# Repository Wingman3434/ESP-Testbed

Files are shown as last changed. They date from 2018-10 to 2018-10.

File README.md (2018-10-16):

## Introduction

Despite decades of research, home automation has yet to make a significant impact on our everyday lives. Many researchers are developing protocols to remove the need for a central controller. These protocols are often developed for the ESP8266, a low-cost Wi-Fi microcontroller. It can be found on the ESP-01 development module, an 8-pin scaled down version of the full ESP8266 microcontroller. With a lack of an onboard serial controller and voltage regulator, the ESP-01 is difficult to program on a large scale. The ESP-Testbed was created to solve the problem of scalability in these IoT research projects. The concept of the ESP-Testbed is a highly scalable, low-cost prototyping system which allows researchers to test ESP8266 protocols and firmware on a large scale.

## Key Features

- Efficiently Flash many ESP-01 modules with any firmware
- Power a full tower of 15 devices
- Centrally manage a large number of ESP towers
- Test WiFi interference in 3 dimensions
- Communicate with a large number of ESP’s via serial

## Software

The ESP Testbed uses a client-server model via TCP sockets. The Raspberry Pi acts as the client, indefinitely attempting to connect to the server. The user starts the server, which accepts all client connection requests. The server imports data from the configuration file processes it and sends commands to the Raspberry Pi. The client is responsible for interfacing with the ESPs, it controls the Pi’s GPIO pins and serial communication. During programming, the Pi will send progress data back to the server, showing the user progress without the need to connect directly to the tower.

## Make or Buy

The ESP Testbed is a fully open source project, allowing you to download the required files and start building your own towers. This task can be a little daunting so the ESP Testbed team is happy to help. For a small fee, we can assemble, test and ship as many towers as you require.

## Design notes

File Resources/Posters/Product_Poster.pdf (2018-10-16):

# IoT Testbed Tower - Overview

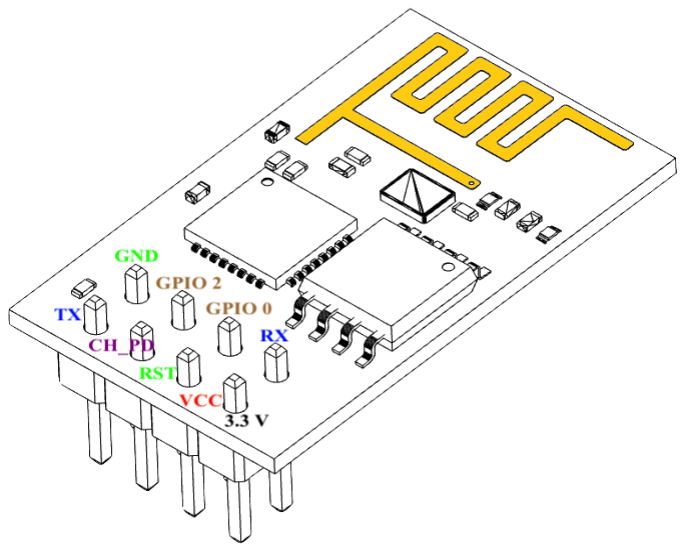
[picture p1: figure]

### Team Name: ESP TESTBED

Student Names: Michael Trifilo, Christopher Rogash School of Engineering, RMIT University, Melbourne, Australia

BACKGROUND & INTRODUCTION

Despite decades of research, home automation has yet to make a significant impact on our everyday lives. Current smart home products rely on the use of a central controller, increasing their cost and complexity.

Our client, Tyler Steane is developing a new IoT protocol which removes the need for a central controller. Steane’s protocol is developed for the ESP8266, a low-cost Wi-Fi microcontroller. It can be found on the ESP-01 development module. With a lack of an onboard serial controller and voltage regulator, the ESP-01 is difficult to program on a large scale.

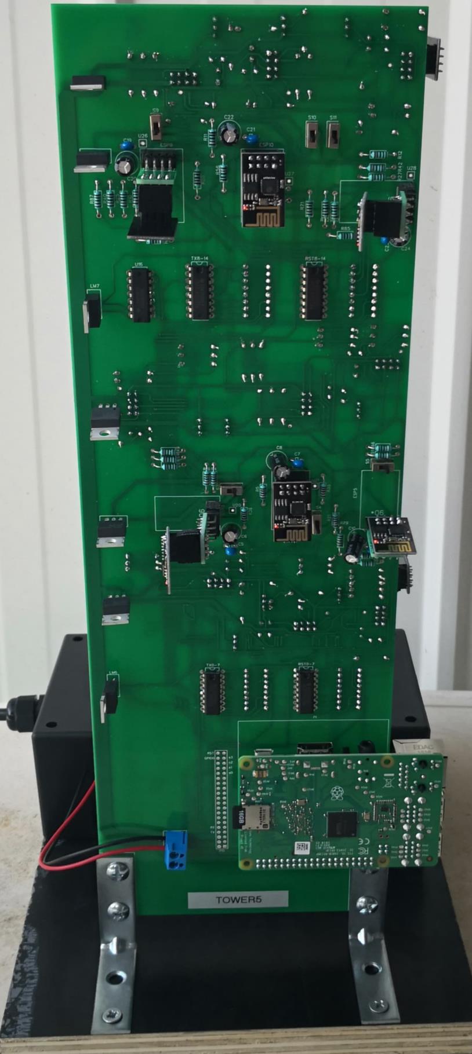
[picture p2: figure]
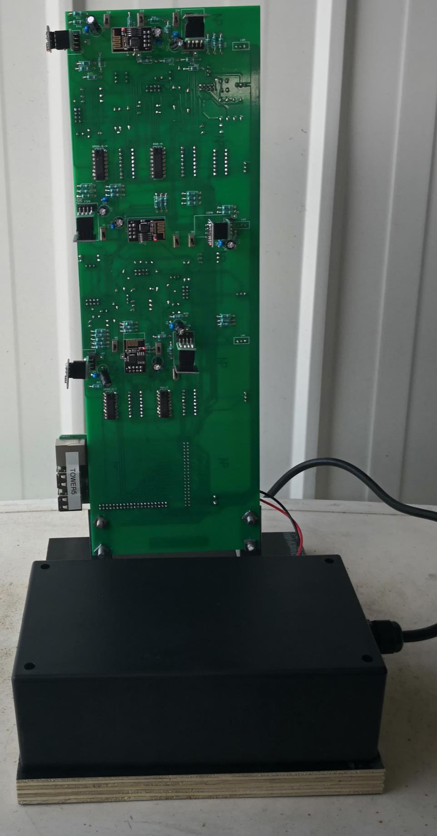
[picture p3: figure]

### www.rmit.edu.au

Figure 3: ESP Tower – Rear View

Figure 2: ESP Tower – Front View

Figure 1: Ai-Thinker ESP-01 Wireframe

ACKNOWLEDGEMENTS
Dr. PJ Radcliffe, PhD student Mr. Tyler Steane

KEY FEATURES
- Efficiently Flash many ESP-01 modules with any firmware.
- Power a full tower of 15 devices.
- Centrally manage a large number of ESP towers.
- Test WiFi interference in 3 dimensions.
- Communicate with a large number of ESP’s via serial.

AIM
Steane’s protocol has been successfully tested on 5 devices. One concern of Steane’s protocol is packet loss due to collision. The ESP Testbed aims to solve this problem by creating compact towers of IoT devices which can be programmed from a single PC. Our goal is to test this on up to 150 devices.

CONCLUSION
The outcome of the ESP Testbed was successful in achieving its initial goal, morphing into a highly scalable, low-cost prototyping system which allows any researcher to test ESP8266 protocols and firmware. The full cost of a tower is approximately $155 AUD with reductions when ordering in bulk. The project has been made open source on GitHub with all documentation, schematics and code made available for anyone to use on their own projects. Further work is planned to continue the development of the ESP Testbed, aiming to increase ease of use and adding extra functionality to the project.

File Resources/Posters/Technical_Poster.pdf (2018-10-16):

# IoT Testbed Tower - Results

DESIGN OF TOWER
Each ESP Tower was made from a set of requirements provided by our client, Tyler Steane. Each tower must:
- Power 15 ESP-01 modules and a Raspberry Pi.
- Provide the ability to remotely program all ESP-01 modules.
- Allow for Wi-Fi testing in 3 dimensions.
- Stand vertically with a sturdy footing.

The PCB’s are split into 4 distinct component sections.
These | are | power, | Pi | control, | communication | via
multiplexers, and the ESP-01 modules.

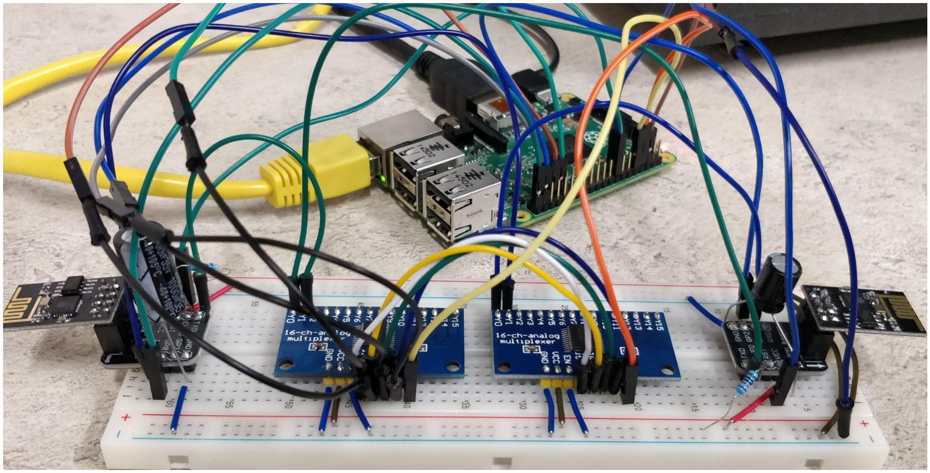
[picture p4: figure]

### www.rmit.edu.au

PROGRAMMING
The ESP Testbed uses a client-server model via TCP sockets. The Raspberry Pi acts as the client, indefinitely attempting to connect to the server. The user starts the server, which accepts all client connection requests. The server imports data from the configuration file, processes it and sends commands to the Raspberry Pi. The client is responsible for interfacing with the ESPs, it controls the Pi’s GPIO pins and serial communication. During programming the Pi will send progress data back to the server, showing the user progress without the need to connect directly to the tower.

KEY ACHIEVEMENTS
- Schematic & PCB Design
- Electronic Prototyping
- PCB Manufacture & Troubleshooting
- Mastering Python Networking
- IoT Development in Arduino IDE
- Plant UML – Diagram design language
- Team Communication Skills
- Time Management
- Formal Report Writing

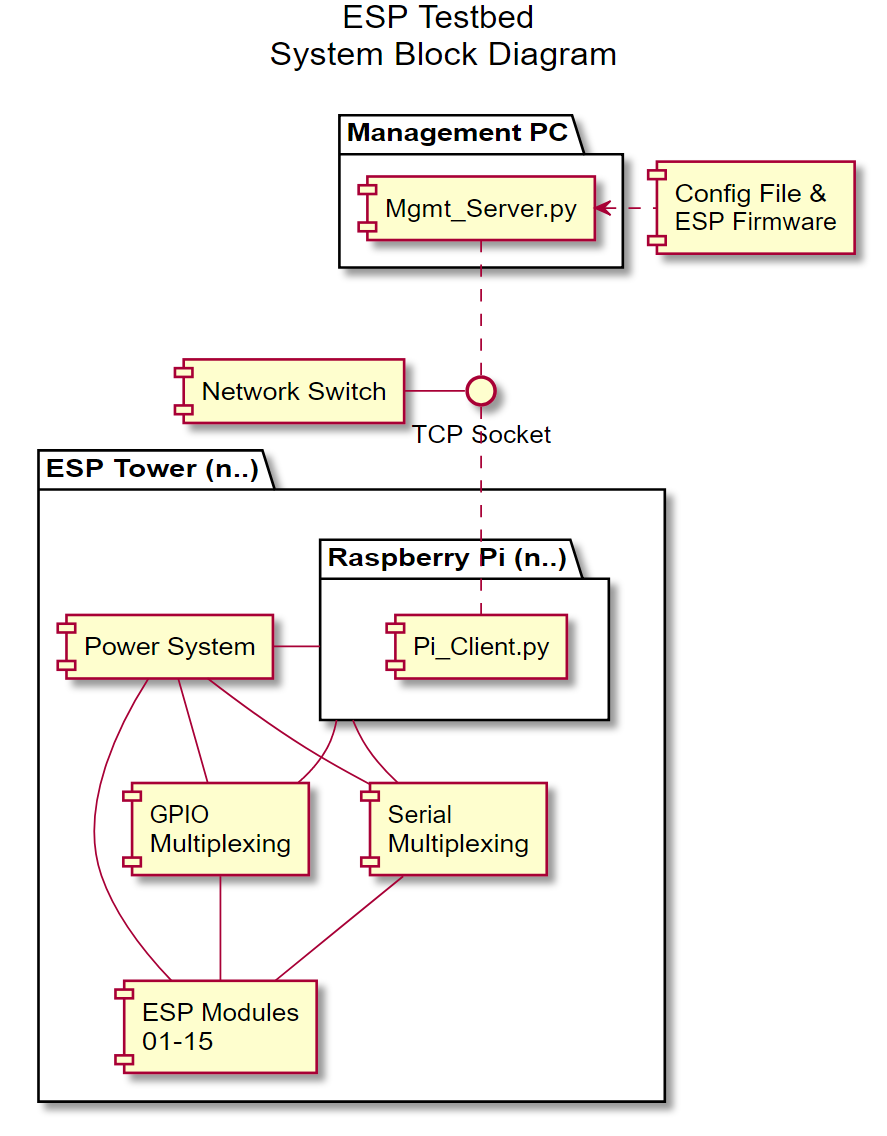
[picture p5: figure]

Figure 1: System Block Diagram

### Team Name: ESP TESTBED

Student Names: Michael Trifilo, Christopher Rogash School of Engineering, RMIT University, Melbourne, Australia

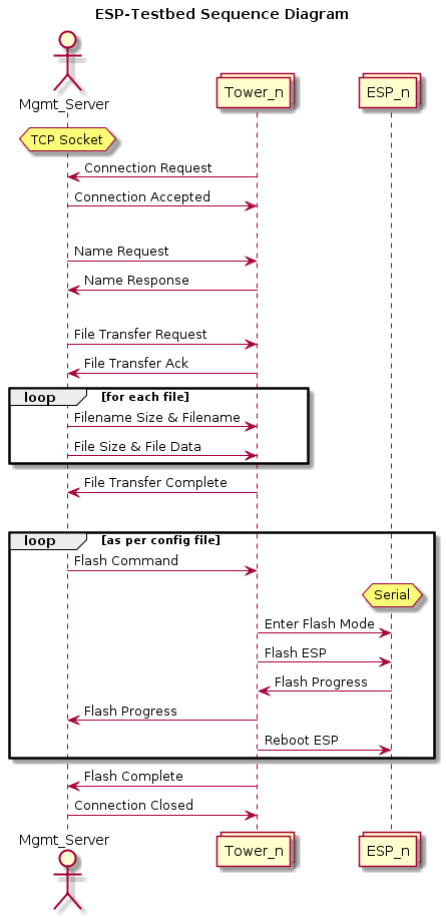
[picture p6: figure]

Figure 2: Software Sequence Diagram

Figure 3: Proof of Concept

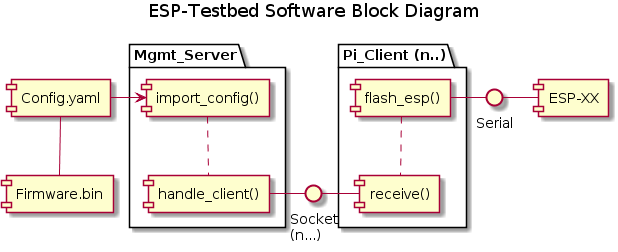
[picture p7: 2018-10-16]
Resources/Diagrams/Software_Block_Diagram_V1.png

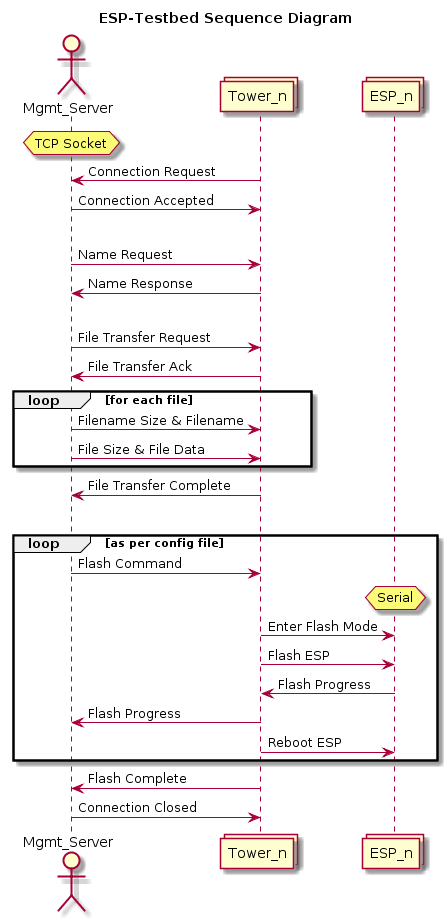
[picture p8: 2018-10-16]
Resources/Diagrams/Code_Sequence_Diagram_V1.png

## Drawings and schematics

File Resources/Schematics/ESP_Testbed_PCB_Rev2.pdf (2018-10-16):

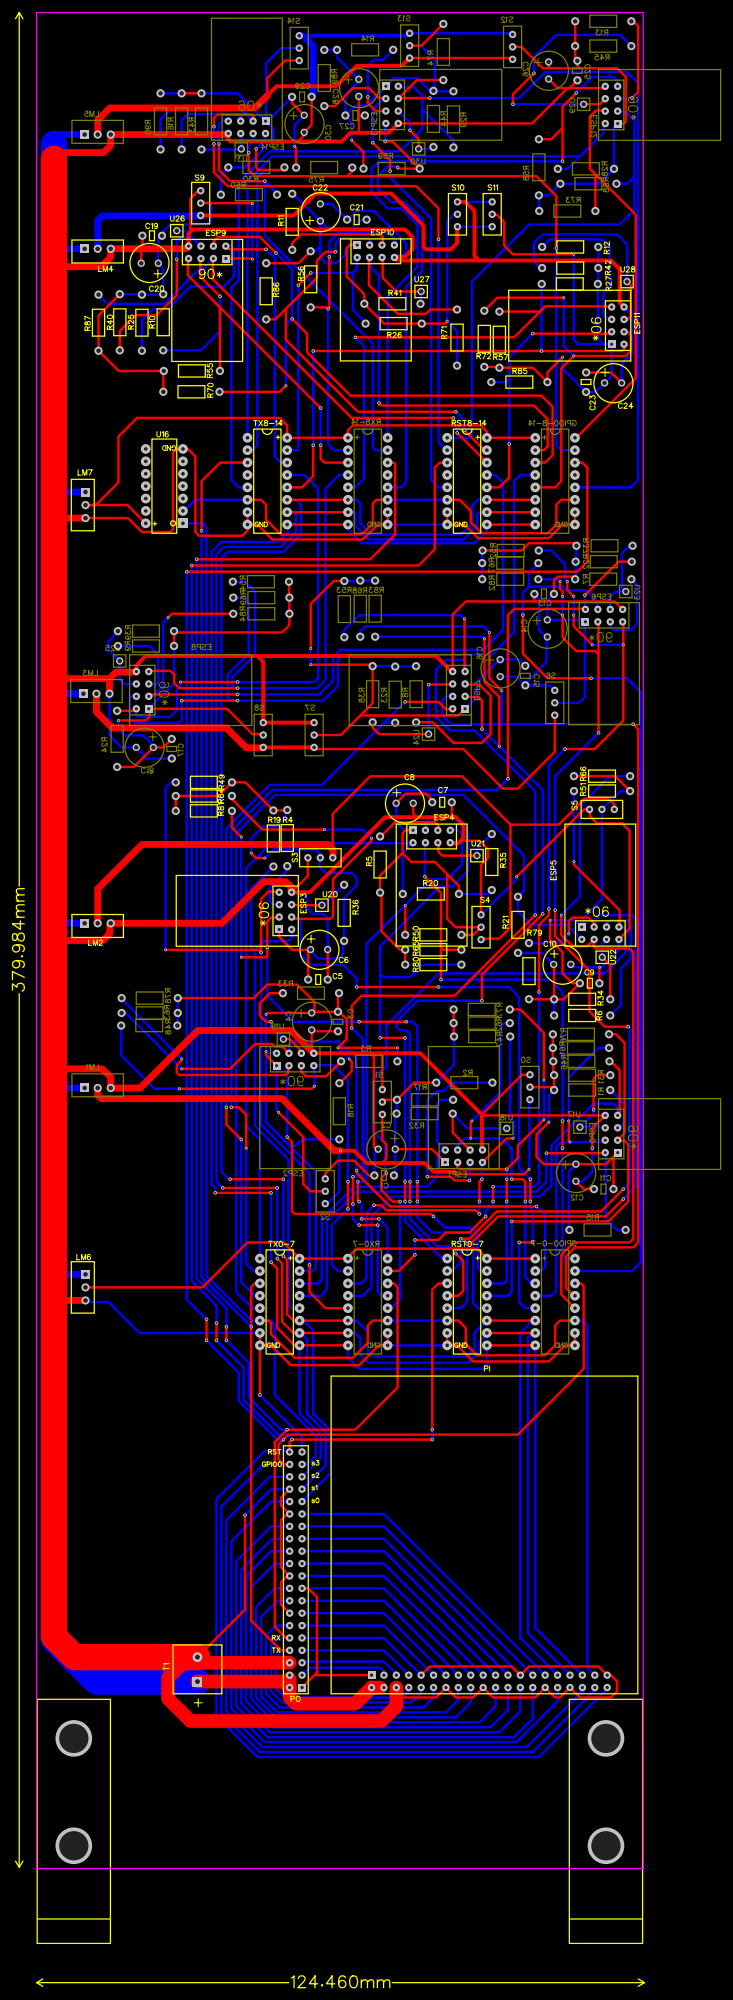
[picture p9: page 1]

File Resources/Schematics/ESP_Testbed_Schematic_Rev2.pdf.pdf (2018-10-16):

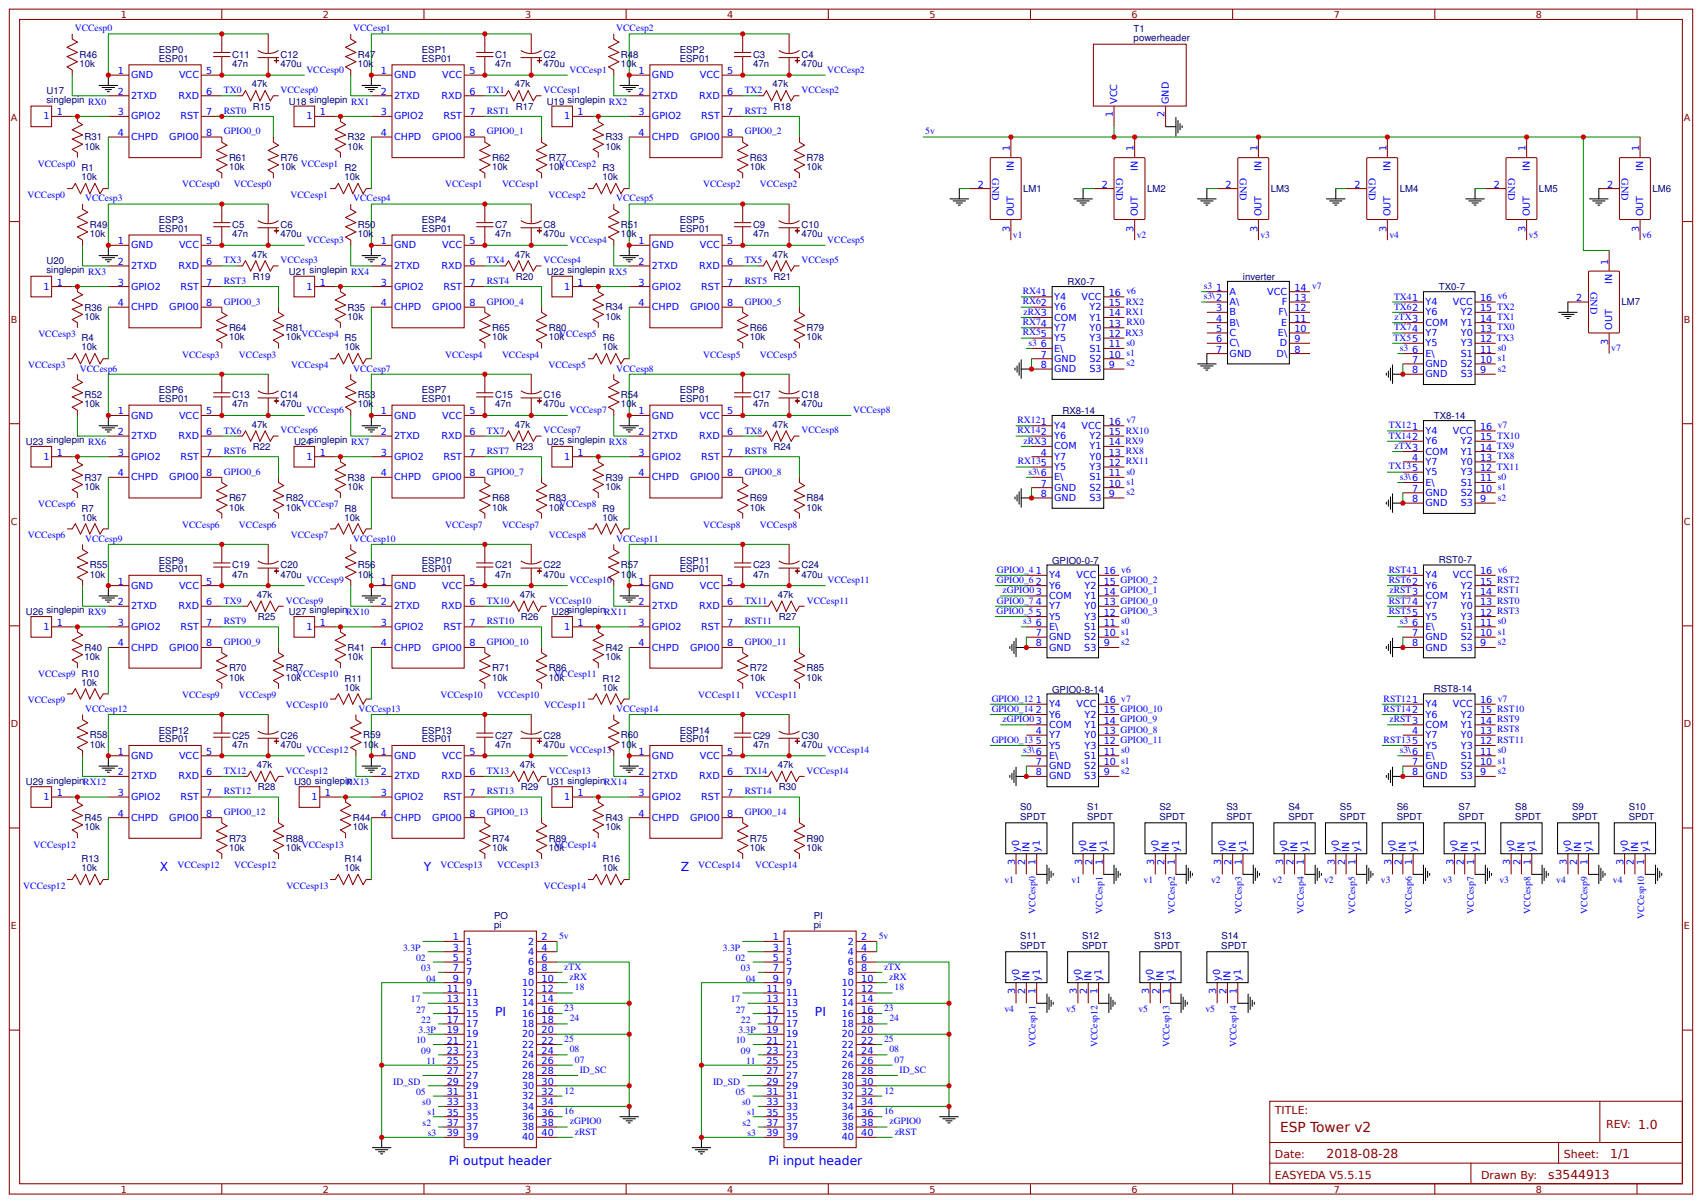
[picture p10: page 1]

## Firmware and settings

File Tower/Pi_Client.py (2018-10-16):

import platform
import RPi.GPIO as GPIO
import serial
from socket import socket, AF_INET, SOCK_STREAM, SOCK_DGRAM
from threading import Thread
import time, os, sys, select, logging, argparse, subprocess

#GPIO Functions
def GPIO_Setup():
    towerlog.debug('GPIO_Setup Started')
    GPIO.setmode(GPIO.BOARD)
    GPIO.setwarnings(False)
    GPIO.setup(S0,GPIO.OUT)
    GPIO.setup(S1,GPIO.OUT)
    GPIO.setup(S2,GPIO.OUT)
    GPIO.setup(S3,GPIO.OUT)
    GPIO.setup(GPIO0,GPIO.OUT)
    GPIO.setup(RST,GPIO.OUT)
    towerlog.debug('GPIO_Setup Complete')
    
def GPIO_Default():
    towerlog.debug('GPIO_Default Started')
    GPIO.output(S0,0)
    GPIO.output(S1,0)
    GPIO.output(S2,0)
    GPIO.output(S3,0)
    GPIO.output(GPIO0,1)
    GPIO.output(RST,1)
    towerlog.debug('GPIO_Default Complete')
    
def esp_selector(esp):
    towerlog.debug('esp_selector Started')
    if int(esp) == 0:
        esp_binary = '0b0000'
    elif int(esp) == 1:
        esp_binary = '0b0001'
    elif int(esp) == 2:
        esp_binary = '0b0010'
    elif int(esp) == 3:
        esp_binary = '0b0011'
    elif int(esp) == 4:
        esp_binary = '0b0100'
    elif int(esp) == 5:
        esp_binary = '0b0101'
    elif int(esp) == 6:
        esp_binary = '0b0110'
    elif int(esp) == 7:
        esp_binary = '0b0111'
    else:
        esp_binary = bin(int(esp))
    return [esp_binary[5], esp_binary[4], esp_binary[3], esp_binary[2]]
    towerlog.debug('esp_selector Complete')
      
def select_esp(array):
    towerlog.debug('select_esp Started')
    GPIO.output(S0,int(array[0]))
    GPIO.output(S1,int(array[1]))
    GPIO.output(S2,int(array[2]))
    GPIO.output(S3,int(array[3]))
    towerlog.debug('select_esp Complete')

def reset_esp(esp, bootmode):
    towerlog.debug('reset_esp Started')
    #Select ESP
    select_esp(esp_selector(esp))
    #Set GPIO Bootmode
    GPIO.output(GPIO0,bootmode)
    #Set RST LOW
    GPIO.output(RST,0)
    time.sleep(1)
    #Set RST HIGH
    GPIO.output(RST,1)
    time.sleep(1)
    towerlog.debug('reset_esp Complete')
    
def flash_esp(esp, port, location, file):
    towerlog.info('Flashing ESP: ' + str(esp))
    #Reset ESP to Program Mode
    reset_esp(esp,0)
    #Build command to call esptool.py
    command = []
    command.append(esptool_path)
    command.append('--port')
    command.append(port)
    command.append('write_flash')
    command.append(location)
    command.append(file)
    #Create subprocess
    flash_shell = subprocess.Popen(command,stdout=subprocess.PIPE)
    while True: #Check output, log and send to server
        cmd_output = flash_shell.stdout.readline().rstrip()
        if cmd_output == '' and flash_shell.poll() is not None:
            break
        else:
            towerlog.info(cmd_output)
            client_socket.send(cmd_output)
    #Reset ESP to Boot Mode
    reset_esp(esp,1)
            
def receive():
    global connected
    try:
        msg = client_socket.recv(BUFSIZ).decode("utf8")
        if msg == 'Name?': # Name Request
            client_socket.send(my_name) # Name Response
        elif msg == 'FILES!': # File Transfer Request
            size = client_socket.recv(16) # Filename Size
            if not size:
                towerlog.info('File Transfer Error!')
            size = int(size, 2)
            filename = client_socket.recv(size) # Filename
            filesize = client_socket.recv(32) # File Size
            filesize = int(filesize, 2)
            file_to_write = open(filename, 'wb')
            chunksize = 4096
            # Recieve File data
            while filesize > 0:
                if filesize < chunksize:
                    chunksize = filesize
                data = client_socket.recv(chunksize)
                file_to_write.write(data)
                filesize -= len(data)
            file_to_write.close() # Write Data to new file
            client_socket.send('Done') # File Transfered
        elif msg == 'Flash':
            size = client_socket.recv(32) # Command Size
            if not size:
                towerlog.info('Flash Command Transfer Error!')
            size = int(size, 2)
            command = client_socket.recv(size) # Command
            command = command.split(' ')
            flash_esp(command[2], serial_port, flash_location, command[3])
            time.sleep(2)
            client_socket.send('Done')
    except: # Connection Error
        connected = False
        client_socket.close()
        time.sleep(2)

def send(message):  #Send Message
    client_socket.send(bytes(message, "utf8"))
    if message == "{quit}":
        client_socket.close()

##Logging
# create logger with 'ESP Logger'
towerlog = logging.getLogger('Tower_Logger')
towerlog.setLevel(logging.DEBUG)
# create file handler which logs everything
fh = logging.FileHandler('Tower_Log.log')
fh.setLevel(logging.DEBUG)
# create console handler with a higher log level
ch = logging.StreamHandler()
ch.setLevel(logging.INFO)
# create formatter and add it to the handlers
formatter = logging.Formatter('%(asctime)s - %(levelname)s - %(message)s')
fh.setFormatter(formatter)
ch.setFormatter(formatter)
# add the handlers to the logger
towerlog.addHandler(fh)
towerlog.addHandler(ch)

## Variables

#Pin Numbers
my_name = platform.node()
S0 = 31
S1 = 33
S2 = 35
S3 = 37
GPIO0 = 38
RST = 40

#Env Variables
esptool_path = '/home/pi/esptool/esptool.py'
serial_port = '/dev/serial0'
flash_location = '0x0'

#Parse Arguments
parser = argparse.ArgumentParser()
parser.add_argument("host", help="IP of the Mgmt PC")
args = parser.parse_args()

#Socket Variables
connected = False
HOST = args.host
PORT = 5000
BUFSIZ = 1024
ADDR = (HOST, PORT)

#Setup GPIO
GPIO_Setup()

#Default GPIO Values
GPIO_Default()

# Main Connection Loop
while True:
    while not connected: # Remake socket and try to connect
        try:
            client_socket = socket(AF_INET, SOCK_STREAM)
            towerlog.info('Attemting to connect to server')
            client_socket.connect(ADDR)
            connected = True
            towerlog.info('Connected to host!')
        except:
            towerlog.info('Connection Timeout')
            connected = False
            time.sleep(2)
    while connected: # When connected call recieve()
        receive()

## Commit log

2018-10-10 Added ESP flash result sent over socket
2018-10-16 Fixed Pi Client Error
    [Pi_Client.py]
2018-10-16 Added Resources + Updated Readme
    [Gerber_BoardOutline.GKO, Gerber_BottomLayer.GBL, Gerber_BottomSilkLayer.GBO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]
